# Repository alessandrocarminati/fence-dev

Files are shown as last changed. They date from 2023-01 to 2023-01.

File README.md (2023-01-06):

# Fence (Poor man's IPMI)

This is the implementation of an IPMI based on ESP6266 WeMos D1 Mini board.
The main requirement is to be cheap.

# Hardware

Here is the list of components:

0. 1 WeMos D1 mini
0. 1 Resistor 220 ohm
0. 1 Resistor 10k ohm
0. 2 4n25 optocoupler
0. 2 1x2 male pin header
0. 1 1x4 male pin header
0. 2 1x8 female pin header
0. 1 Fence board

This is an example of the board needed to have the functionality:

Front view

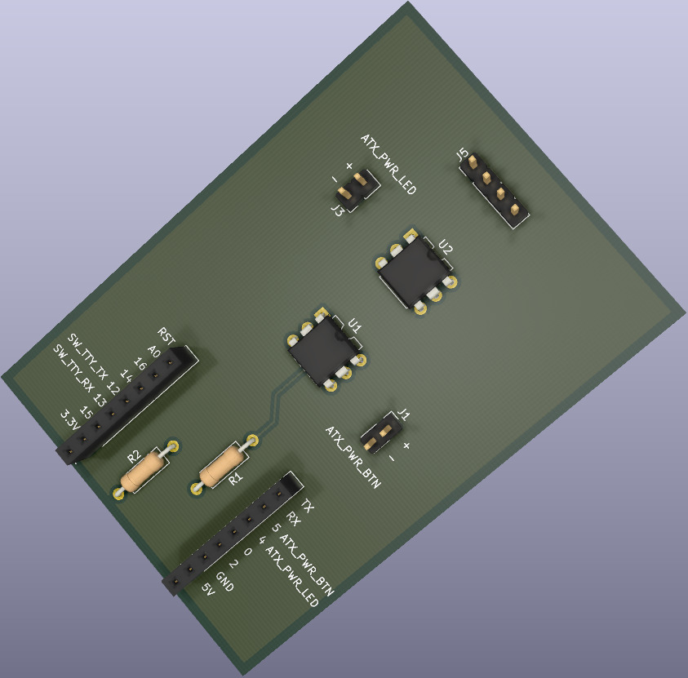
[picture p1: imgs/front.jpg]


Back view

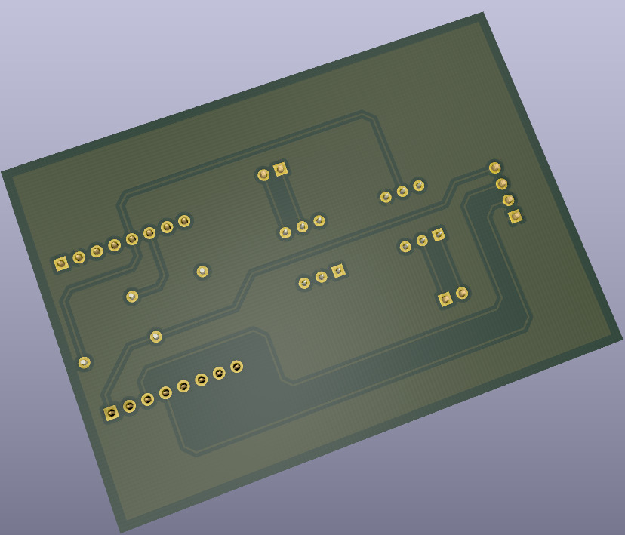
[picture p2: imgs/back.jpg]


The `hw` directory contains the hardware board design file written using kicad.

# Software

The software is a simple Arduino schetch.

Required libraries for build it:

* ESP8266WebServer (https://github.com/codemee/ESP8266WebServer)
* SoftwareSerial (https://github.com/plerup/espsoftwareserial)
* WebSockets (https://github.com/Links2004/arduinoWebSockets)

## Note

HTML pages are gzipped binary blobs included statically as a char array.
To generate them, please execute the `build_header.sh` script before
compiling the schetch using the Arduino ide.

# Known issues

The Wemos D1 mini has the hardware serial used by the USB2Serial device.
For this reason it can not be used to link the controlled device.
To have the serial monitor feature, a software serial is used.
Apparently it can not exceed the 38400 bps, and at that speed, 
sopradic transmission errors can occur.

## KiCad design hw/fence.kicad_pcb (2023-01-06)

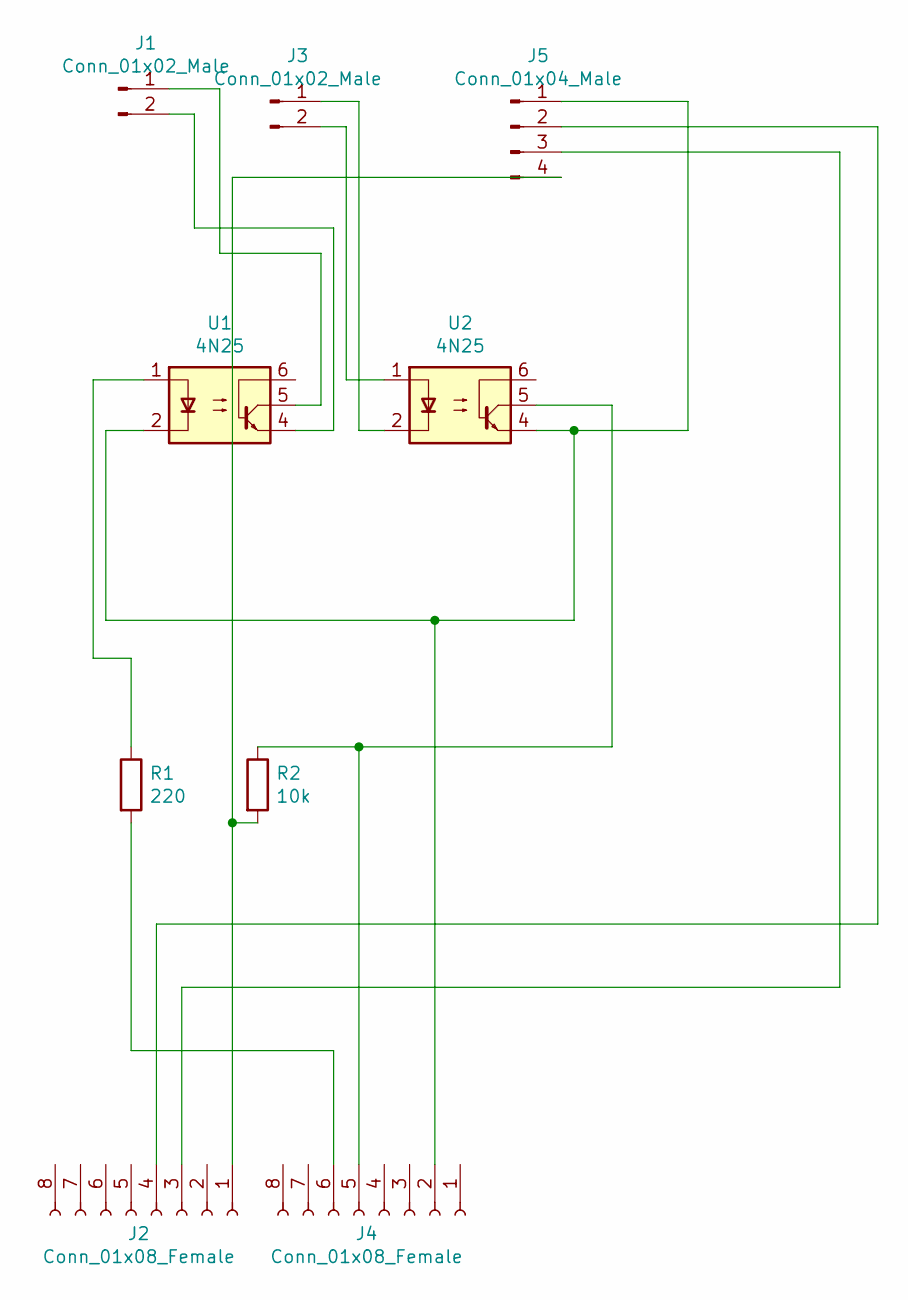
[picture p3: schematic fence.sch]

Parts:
J1, J3: Conn_01x02_Male; PinHeader_1x02_P2.54mm_Vertical
J2, J4: Conn_01x08_Female; PinSocket_1x08_P2.54mm_Vertical
J5: Conn_01x04_Male; PinHeader_1x04_P2.54mm_Vertical
R1: 220; R_Axial_DIN0207_L6.3mm_D2.5mm_P10.16mm_Horizontal
R2: 10k; R_Axial_DIN0207_L6.3mm_D2.5mm_P10.16mm_Horizontal
U1, U2: 4N25; DIP-6_W7.62mm

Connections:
unnamed: J1.1, U1.5
unnamed: J1.2, U1.4
unnamed: J2.1, J5.4, R2.2
unnamed: J2.3, J5.3
unnamed: J2.4, J5.2
unnamed: J3.1, U2.2
unnamed: J3.2, U2.1
unnamed: J4.2, J5.1, U1.2, U2.4
unnamed: J4.5, R2.1, U2.5
unnamed: J4.6, R1.2
unnamed: R1.1, U1.1

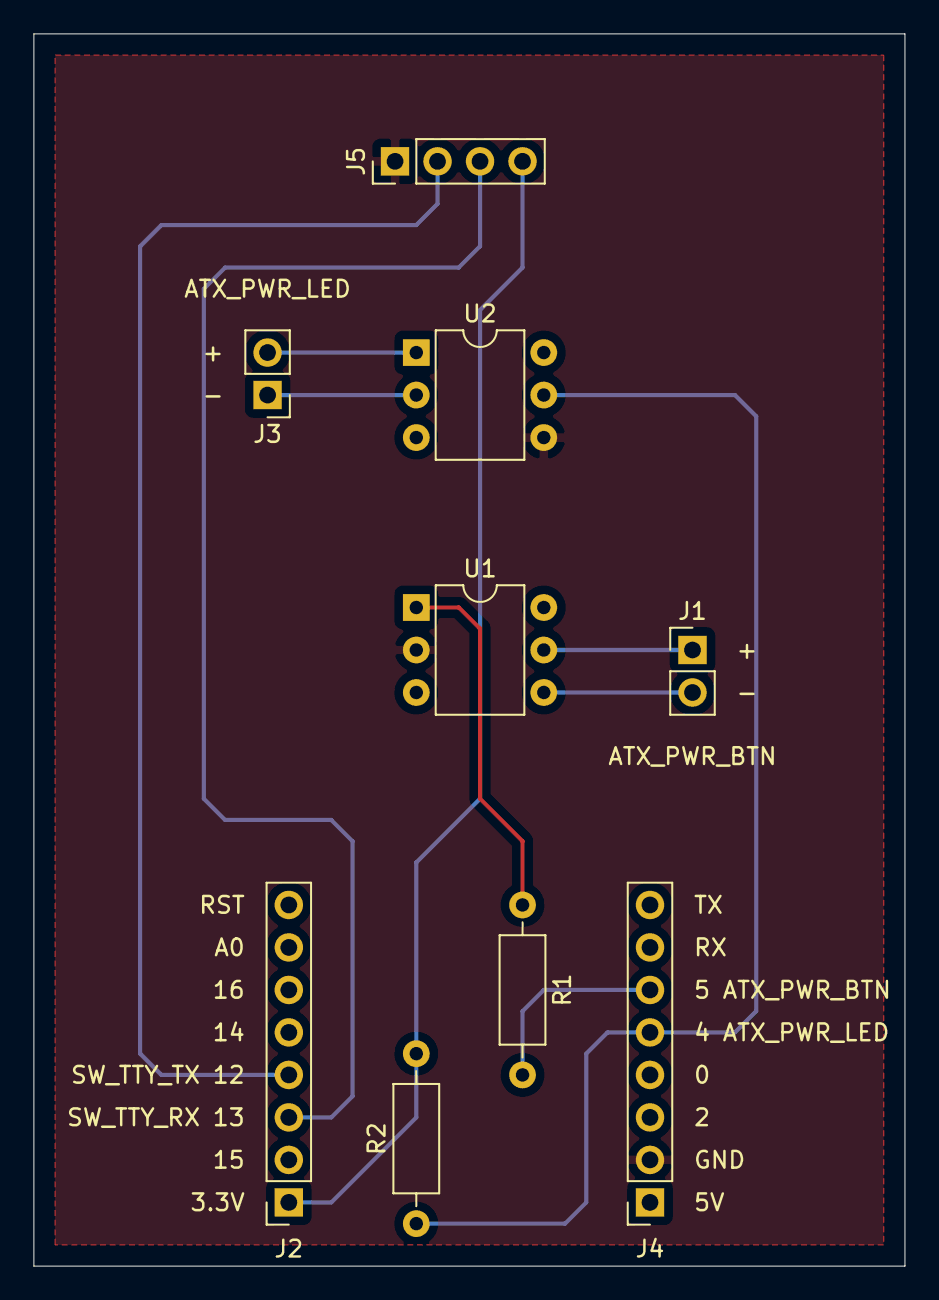
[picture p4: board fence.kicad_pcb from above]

Board: 2 copper layers, 52.1 x 73.7 mm, 9 parts (0 on the bottom side), 11 nets.

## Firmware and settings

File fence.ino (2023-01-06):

#include <ESP8266WiFi.h>
#include <ESP8266WebServer.h>
#include <Wire.h>
#include <Arduino.h>
#include <SoftwareSerial.h>
#include <EEPROM.h>
#include "htmls.h"
#include <WebSocketsServer.h>
#include "base64_utils.h"

#define DEBUG_ESP_WIFI
#define SHORT_PULSE 500
#define LONG_PULSE 5000
#define LEN_BUF 1024
#define TCP_PORT 14550
#define WS_PORT 14551
#define SERIAL_BAUDRATE 115200
#define SW_SERIAL_BAUDRATE 38400 // do not exceed 38400 on esp8266
#define HTTP_PORT 80
#define SW_TTY_TX 12
#define SW_TTY_RX 13
#define ATX_PWR_BTN 5
#define ATX_PWR_LED 4
#define UP HIGH
#define DW LOW

#define HELP "\n\
resource  | output                | args\n\
getstate  | json status           | no args \n\
setstate  | manual rele & status  | 1st:\"on\" switch on, \"off\" switch off\n\
WifiSET   | set new ssid & pass   | 1st=ssid, 2nd=password\n\
You can connect a telnet client at TCP:14550\n"


const char* def_ssid = "SetupThing";
const char* def_password = "SetupThing";

ESP8266WebServer server(HTTP_PORT);
WiFiServer serverTCP( TCP_PORT );
WebSocketsServer webSocket = WebSocketsServer(WS_PORT);
SoftwareSerial sw_tty;

int mtempi=0;
int TIME=30000;
float mtemp[8];
char achBuf[LEN_BUF];
size_t sBytesAvailible;
size_t sBytesRead;
int currentWS=-1;


void setup() {
	char	*buf;
	char	curr_ssid[32];
	char	curr_password[32];
	char	*ssid=curr_ssid, *password=curr_password;
	int	addr=0, cnt;

	memset(ssid, 0, 32);
	memset(password, 0, 32);
	mtempi=0;
	for (int i=0;i<8;i++) mtemp[i]=0;
	Serial.begin(SERIAL_BAUDRATE);
	sw_tty.begin(SW_SERIAL_BAUDRATE, SWSERIAL_8N1, SW_TTY_RX, SW_TTY_TX, false);
	delay(10);
	pinMode(ATX_PWR_BTN,OUTPUT);
	pinMode(ATX_PWR_LED,INPUT);
	EEPROM.begin(512);
	if (EEPROM.read(511)==0xaa) {
		Serial.println("eeprom wifi conf exists!");
		while (EEPROM.read(addr)!='\0') {
			curr_ssid[addr]=EEPROM.read(addr);
			addr++;
			}
		curr_ssid[addr]='\0';    
		addr=32;
		while (EEPROM.read(addr)!='\0') {
			curr_password[addr-32]=EEPROM.read(addr);
			addr++;
			}
		curr_password[addr-32]='\0';
		password=curr_password;
		ssid=curr_ssid;
		} else {
			Serial.println("eeprom wifi conf does nor exist!");
			ssid=(char *)def_ssid;
			password=(char *)def_password;
			}
	Serial.println("Settings:");     
	Serial.println(ssid);
	Serial.println(password);
	buf=(char *)ssid;

	Serial.println();
	Serial.print("Connecting to ");
	Serial.println(ssid);
	Serial.flush();
	WiFi.begin(ssid, password);

	cnt=0;
	while (WiFi.status() != WL_CONNECTED) {
		if (cnt==65) {
			buf=(char *)def_ssid;
			WiFi.begin(def_ssid, def_password);
			Serial.println("Bakcup default");
			}
		delay(500);
		Serial.print(".");
		cnt++;
		}
	Serial.println("");
	Serial.println("WiFi connected");
	serverTCP.begin();
	server.begin();
	Serial.println("Web server running. Waiting for the ESP IP...");
	delay(10000);

	Serial.println(WiFi.localIP());
	IPAddress x=WiFi.localIP();
	char *buf2=(char *)calloc(20,1);
	for (int i=0;i<4;i++) {itoa(x[i],buf2+strlen(buf2),10);buf2[strlen(buf2)]='.';}
	buf2[strlen(buf2)-1]='\x00';
	Serial.println(buf2);
	delay(2000);
	server.on("/help", MainHelp);
	server.on("/getstate", getstate);
	server.on("/setstate", button);
	server.on("/WifiSET", WifiSET);

	server.on("/on.gif", serveon);
	server.on("/off.gif", serveoff);
  server.on("/wsconsole", servewsconsole);
	server.on("/setup", servesetup);
	server.on("/", servehome);
	server.on("/css", servecss);
	server.onNotFound(handleNotFound);
  webSocket.begin();
  webSocket.onEvent(webSocketEvent);
}

void serve_static(const char *f, int fsize, const char *content_type){
	Serial.println("Serving static content:");
	server.sendHeader("Content-Encoding", "gzip");
	server.send_P(200, content_type, f, fsize);
}

void serve_static_img(const char *f, int fsize){
	Serial.println("Serving static img:");
	server.send_P(200, "image/gif", f, fsize);
}

void serveoff(){
	Serial.println("serve off");
	serve_static_img(off_icon, sizeof(off_icon));
}

void serveon(){
	Serial.println("serve on");
	serve_static_img(on_icon, sizeof(on_icon));
}

void servehome(){
	Serial.println("serve home");
	serve_static(home_html, sizeof(home_html), "text/html");
}


void servecss(){
	Serial.println("serve CSS");
	serve_static(style_css, sizeof(style_css), "text/css");
}


void servesetup(){
  Serial.println("serve setup");
  serve_static(setup_html, sizeof(setup_html), "text/html");
}
void servewsconsole(){
  Serial.println("serve wsconsole");
  serve_static(wsconsole_html, sizeof(wsconsole_html), "text/html");
}

void MainHelp()
{
	server.send(200, "text/plain",HELP);
}


void WifiSET(){
	//Serial.println("WifiSET");
	String ssid = server.arg(0);
	String password = server.arg(1);
	String s="OK";

	if ((ssid.length()<32)&&(password.length()<32)&&(ssid.length()>5)&&(password.length()>5)){
		for (int i=0; i<32;i++){
			if (i<ssid.length()) {
				EEPROM.write(i, ssid[i]);
				} else { 
					EEPROM.write(i, 0);
					}
			}
		for (int i=0; i<32;i++){
			if (i<password.length()) {
				EEPROM.write(i+32, password[i]);
				} else { 
					EEPROM.write(i+32, 0);
					}
			}
		EEPROM.write(511, 0xaa);
		EEPROM.commit();
		server.send(200, "text/plain",s);
		delay(1500);
		ESP.restart();
		} else {
			s="invalid\n";
			server.send(200, "text/plain",s);
			}
}

void handleNotFound(){
	server.send(404, "text/plain","You hit a page that does not exist.\n");
}

void button(){
	Serial.println("button");
	String stat = server.arg(0);
	String s;
	s="not supported!\n";
	if (stat=="pulse") {//
		s="sent pulse";
		digitalWrite(ATX_PWR_BTN, UP);
		delay(SHORT_PULSE);
		digitalWrite(ATX_PWR_BTN, DW);
		}
	if (stat=="force") {
		s="sent force";
		digitalWrite(ATX_PWR_BTN, UP);
		delay(LONG_PULSE);
		digitalWrite(ATX_PWR_BTN, DW);
		}
	server.send(200, "text/plain",s);
}


void getstate(){
	//Serial.println("getstate");
	String s;
	int val;

	val = digitalRead(ATX_PWR_LED);
	if (val==1) s="off"; 
		else s="on";
	server.send(200, "text/plain",s);
}

void raw_telnet(){
	WiFiClient client = serverTCP.available();
	if (client) {
		Serial.println("client attached");
		while ( client.connected() ) {
			server.handleClient();
			if ( ( sBytesAvailible = client.available() ) > 0 ) {
				if ( sBytesAvailible > LEN_BUF ) sBytesAvailible = LEN_BUF;
					sBytesRead = client.readBytes( &achBuf[0], sBytesAvailible );
					sw_tty.write( &achBuf[0], sBytesRead );
					}
				if ( ( sBytesAvailible = sw_tty.available() ) > 0 ) {
					if (sBytesAvailible > LEN_BUF) sBytesAvailible = LEN_BUF;
					sBytesRead = sw_tty.readBytes( &achBuf[0], sBytesAvailible );
					client.write( &achBuf[0], sBytesRead );
					}
				}
    Serial.println("client disconnected");
		}
}

void webSocketEvent(uint8_t num, WStype_t type, uint8_t * payload, size_t length) {

Serial.printf("webSocketEvent num=%d, type=%d\n", num, type);
    switch(type) {
        case WStype_DISCONNECTED:
            Serial.printf("[%u] Disconnected!\n", num);
            currentWS=-1;
            break;
        case WStype_CONNECTED:{
            IPAddress ip = webSocket.remoteIP(num);
            Serial.printf("[%u] Connected from %d.%d.%d.%d url: %s\n", num, ip[0], ip[1], ip[2], ip[3], payload);
            webSocket.sendTXT(num, "Connected");
            currentWS=num;
            }
            break;
        case WStype_TEXT:
            Serial.printf("[%u] get Text: %s\n", num, payload);
            sw_tty.write(payload, length);
            sw_tty.write("\n", 1);
            break;
        case WStype_BIN:
            Serial.printf("[%u] get binary length: %u\n", num, length);
            break;
    }
}
void wssend(){
  char b64_buf[512];
  int  b64sz;
  
    if (currentWS>=0){
          if ( ( sBytesAvailible = sw_tty.available() ) > 0 ) {
               if (sBytesAvailible > LEN_BUF-1) sBytesAvailible = LEN_BUF-1;
               sBytesRead = sw_tty.readBytes( &achBuf[0], sBytesAvailible );
               achBuf[sBytesRead-1]='\0';
               Serial.println("#1");
               Serial.println(achBuf);
               b64sz=b64_encode(b64_buf, achBuf, sBytesRead);
               Serial.println("#2");
               Serial.println(b64_buf);
               String t = String(b64_buf);
               Serial.println("#3");
               Serial.println(t);
               Serial.printf("[%u] get Text: %s\n", currentWS, achBuf);
               webSocket.sendTXT(currentWS, t );
               }
          }
}

void loop() {
	server.handleClient();
	raw_telnet();
  webSocket.loop();
  wssend();
}

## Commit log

2022-12-31 fix HW: wemos header distance
    [fence.kicad_pcb]
2022-12-31 Fix: WeMos pin5 leftover
    [fence.kicad_pcb, fence.sch]
2023-01-03 PCB and hompage updated
    [fence.kicad_pcb]
2023-01-06 Bundle update
    * pcb refactor & fixes
    * schetch minor cosmethics
    * html buttons rename and synchronization with indicators
    [fence.kicad_pcb, fence.sch]
